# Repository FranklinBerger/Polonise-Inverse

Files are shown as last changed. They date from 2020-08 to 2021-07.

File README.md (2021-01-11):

# Calculatrice Polonaise Inversse

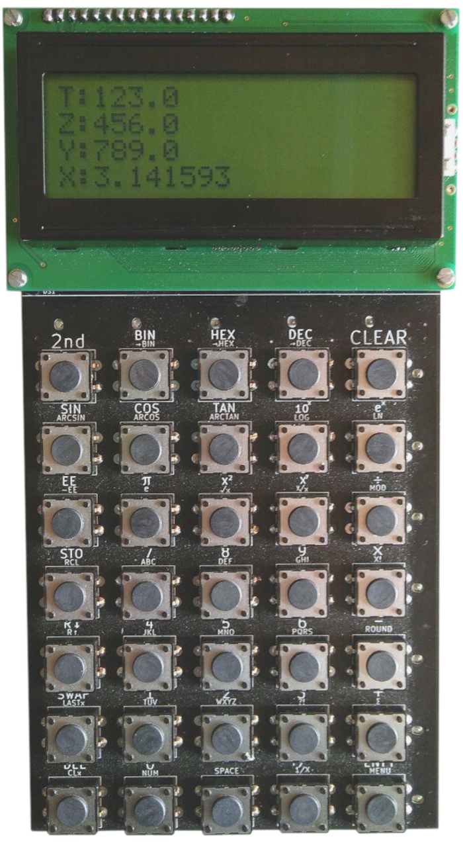
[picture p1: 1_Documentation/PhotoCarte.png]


<p><strong>/!\ Projet en cours de développement vers une verssion stable et correctement doccumentée /!\</strong></p>

Commencé dans le cadre d'un mois de découverte de l'électronique, ce projet consiste en une calculatrice avec [notation en polonaise inversse](https://fr.wikipedia.org/wiki/Notation_polonaise_inverse) dont le hardware est propice à la découverte et l'initiation à l'électronique, soit:
* Montage
* Développement
* Mesures & Dépannage
* Programation

Basée sur ESP32 et dévelopée sur un firware [Micropython](https://github.com/micropython), elle est propice à une compréhenssion de sa structure fondamentale et à des réalisations pratique très rapidement

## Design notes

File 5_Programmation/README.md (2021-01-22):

# Historique des versions
## V1: 22 Janvier 2021
Première version entière, comprenant
* Fonctionnement de base de la caulculatrice (gestion de l'écrant, du clavier, etc...)
* Fonctionnement de toutes les opérations mathématiques disponibles
* Fonctionnement de la gestion de la pile

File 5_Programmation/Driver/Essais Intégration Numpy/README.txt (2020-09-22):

Dans le but de rendre plus puissante et précise la calculatrice, une tentative d'intégrer la bibliothèque numpy a été réalisé. Celui-ci s'est avéré complexe car, hors problèmes de compatibilité dont quelques avancées ont déjà été réalisées (voir backend.py), la plus grande limite rencontrée a été la flash du uC que la bibliothèque surchargeait à l'initialisation (d'où la "compression" du code au travers de mpy-cross). Cette tentative a été abandonnée.

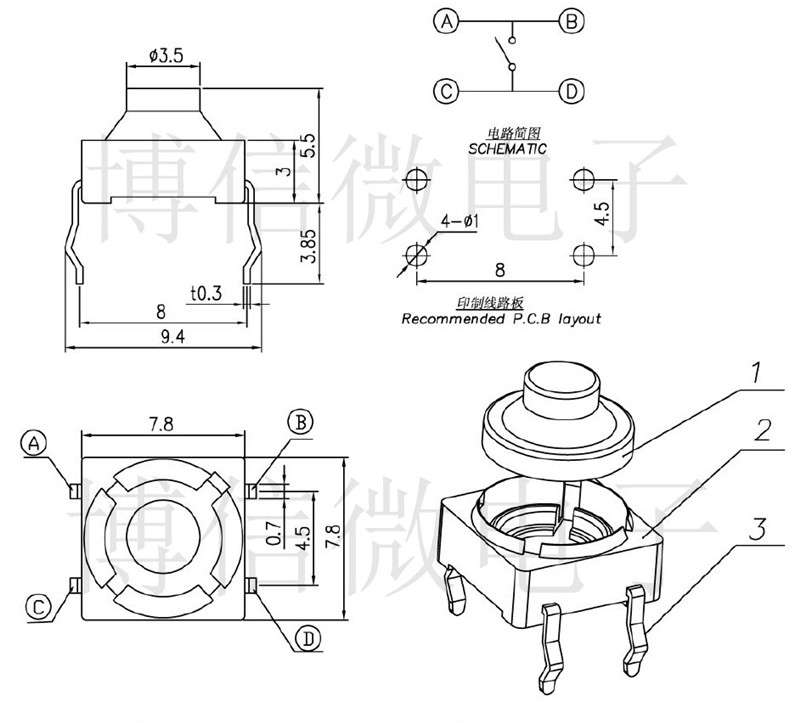
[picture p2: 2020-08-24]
3_Datasheets/BP.jpg

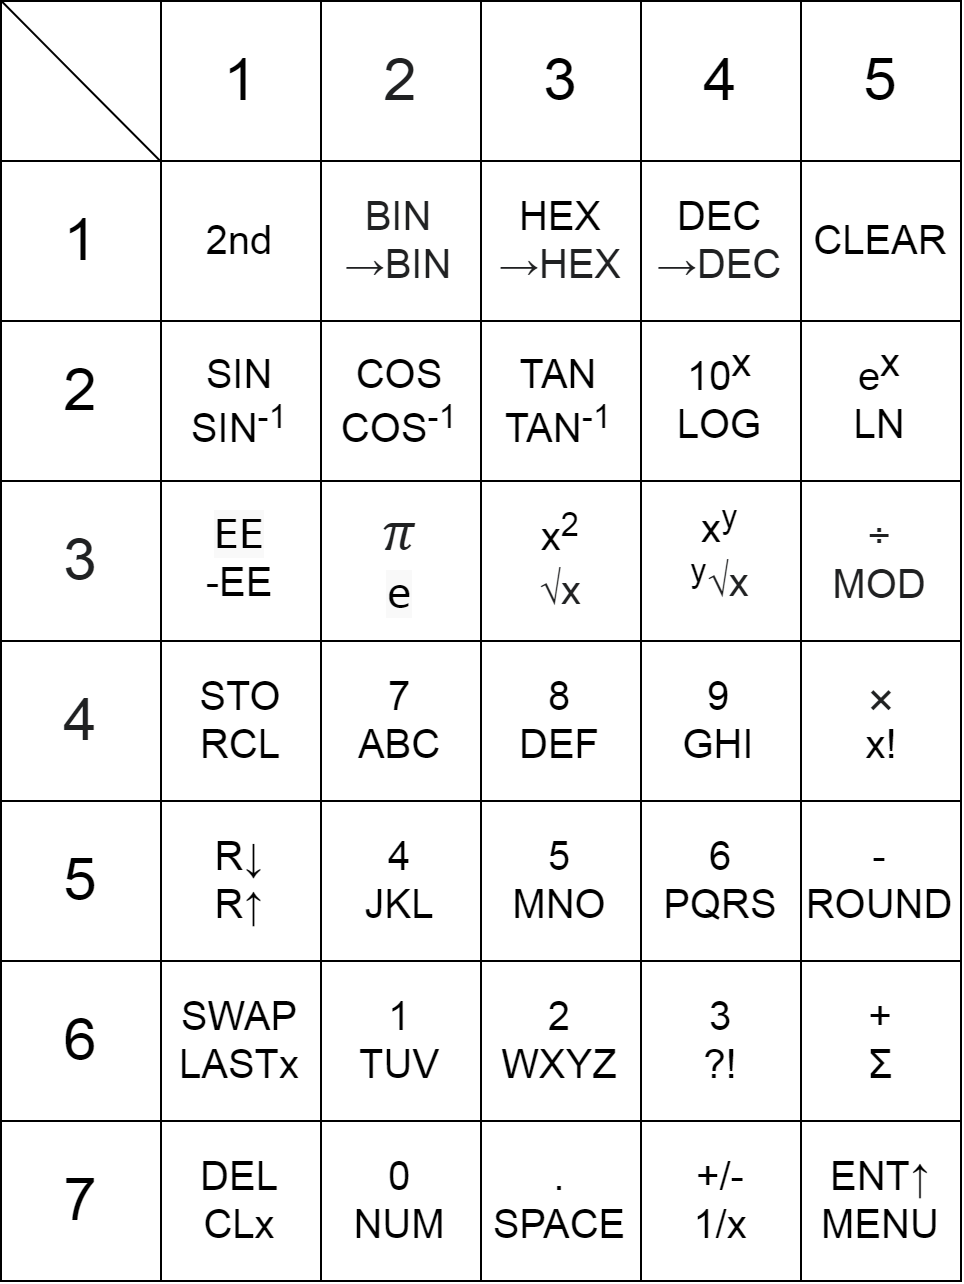
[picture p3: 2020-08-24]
1_Documentation/Clavier.png

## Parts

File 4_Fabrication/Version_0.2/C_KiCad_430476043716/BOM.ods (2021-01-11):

Référence | Valleur | N° Digikey | N° Divers | Qtt | Prix/Pce | Prix | Remarque
BT1 - 1 | Litium 18650 3.7[V] | 1832-1050-ND | Conrad 1558873 - 62 | 1 | 5,95 | 5,95
BT1 - 2 | Battery Holder | BK-18650-PC2-ND | Conrad 651027 - 62 | 1 | 3,45 | 3,45
> C1, C2, C6-C17 | 100[nF] | 399-C1206C104K5RAC7800CT-ND |  | 14 | 0,0413 | 0,5782
> C3, C4 | 33[μF] | 399-4788-1-ND |  | 2 | 0,97 | 1,94
> D1-D13 | 1206 Led rouge | 754-1158-1-ND |  | 13 | 0,27 | 3,51
DS1 - 1 | LCD2004A | NHD-0420DZ-FL-YBW-33V3-ND |  | 1 | 23,25 | 23,25
DS1 - 2 | Pin Header & receptacle 1x16 | 732-5327-ND & S7014-ND | Conrad 733779 - 62 | 1 | 1,15 | 1,15
DS1 - 3 | 4 x Vis + Ecrous + Rondelle + Collon. M2,5 |  |  | 4 | 0,34 | 1,36
J1 - 1 | FT232RL + Câble Mini-USB B | 768-1317-ND |  | 1 | 7,78 | 0, | Pour programation, non-consomable
J1 - 2 | Conn pour J1 | S5481-ND |  | 1 | 0,66 | 0,66
L1 | 2.2[μH] | 587-3544-1-ND |  | 1 | 0,1076 | 0,1076
> Q1-Q6 | BC856B | BC856BLT3GOSCT-ND |  | 6 | 0,0051 | 0,0306
> R1, R2, R25, R27, R29, R31, R33, R36 | 1[KΩ] | 311-1.0KERCT-ND |  | 8 | 0,0249 | 0,1992
> R3, R4, R17-R24, R26, R28, R30, R32, R34 | 10[KΩ] | 311-10KERCT-ND |  | 15 | 0,0249 | 0,3735
> R5-R16, R37 | 330[Ω] | 311-330FRCT-ND |  | 13 | 0,0291 | 0,3783
R35 | 5.6[Ω] | 311-5.60FRCT-ND |  | 1 | 0,14 | 0,14
RV1 | 10[KΩ] | 987-1008-1-ND |  | 1 | 1,27 | 1,27
> SW1, SW2 | BP Wuerth_4.5x6.5mm | 450-1647-ND |  | 2 | 0,1216 | 0,2432
> SW3-SW37 | BP 430476043716 12x12mm | 430476043716-ND |  | 35 | 0,54 | 18,9
SW38 | Switch SK-12F14 | Distrelek 135-11-185 |  | 1 | 0,63 | 0,63
U1 - 1 | Wavga_TP4056_Module |  |  | 1 | 1, | 1,
U1 - 2 | Pin Header 1x2 & 2x2 |  |  | 6 | 0,001 | 0,006
U2 | TPS63001 | 296-19643-1-ND |  | 1 | 2,21 | 2,21
U3 | ESP32-WROOM-32 | 1904-1010-1-ND | Conrad 1925467 - 62 | 1 | 3,8 | 3,8
U4 | PCF8574A | 568-1074-1-ND |  | 1 | 1,44 | 1,44
Print | Print |  |  | 1 | 16 | 16, | Via Eurocircuit, 20pcs Noir
 |  |  |  |  | Total: | 88,5766
 |  |  |  |  | 296-19643-1-ND
 |  |  |  |  | 1904-1010-1-ND
 |  |  |  |  | 568-1074-1-ND

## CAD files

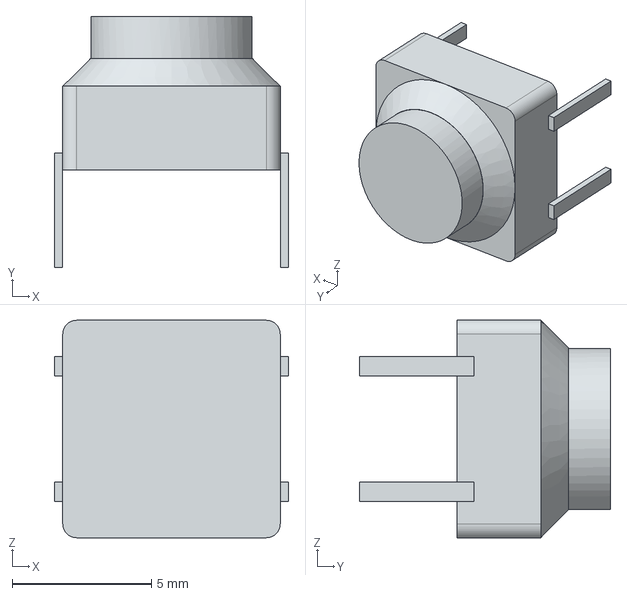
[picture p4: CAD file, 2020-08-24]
4_Fabrication/Version_0.2/C_KiCad_430476043716/G77.stp
8.40 x 9.00 x 7.80 mm

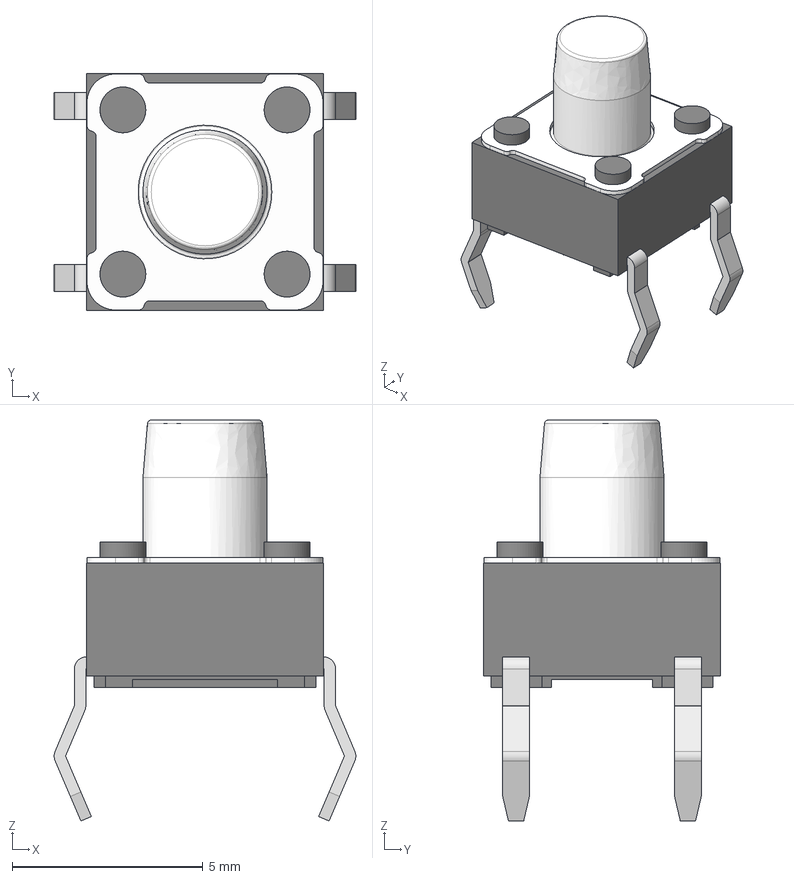
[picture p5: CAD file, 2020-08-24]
4_Fabrication/Version_0.2/C_KiCad_430476043716/shapes3D/SW_Wuert_6.5x4.5.stp
7.90 x 6.20 x 10.5 mm

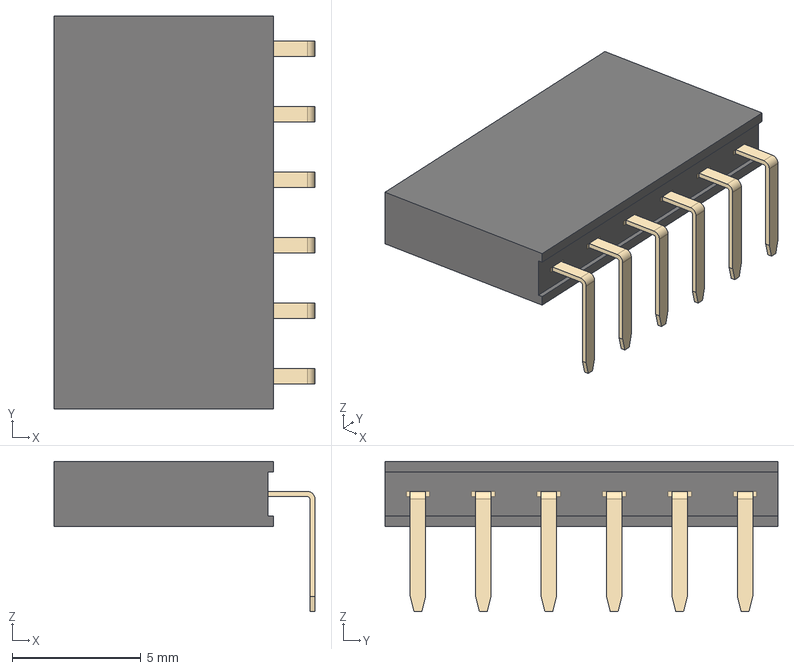
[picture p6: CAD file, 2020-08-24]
4_Fabrication/Version_0.2/C_KiCad_430476043716/shapes3D/PinSocket_1x06_P2.54mm_Horizontal.step
10.1 x 15.2 x 5.84 mm

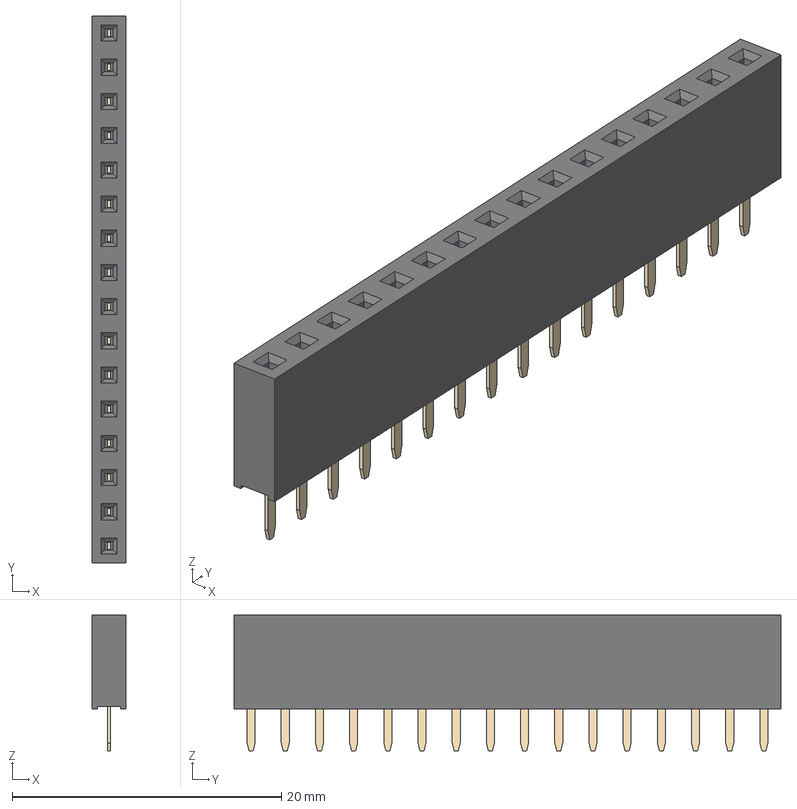
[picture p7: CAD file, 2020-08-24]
4_Fabrication/Version_0.2/C_KiCad_430476043716/shapes3D/PinSocket_1x16_P2.54mm_Vertical.step
2.54 x 40.6 x 10.1 mm

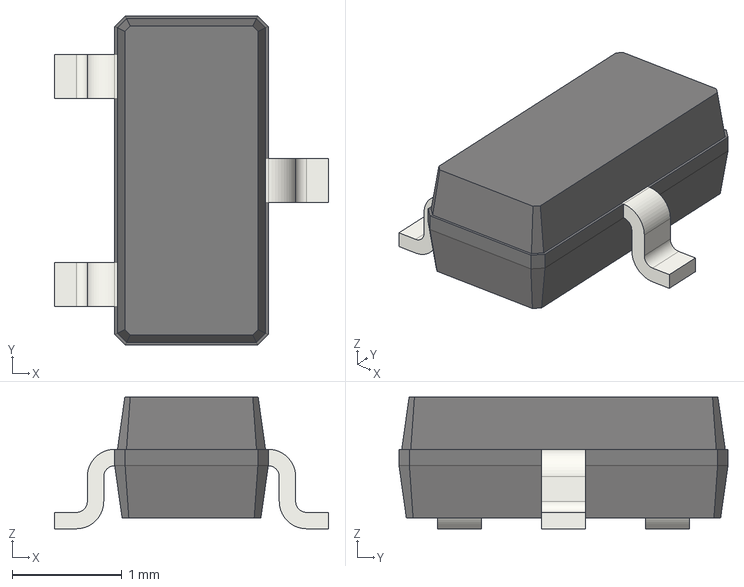
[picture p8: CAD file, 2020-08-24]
4_Fabrication/Version_0.2/C_KiCad_430476043716/shapes3D/SOT-23.step
2.50 x 3.00 x 1.20 mm

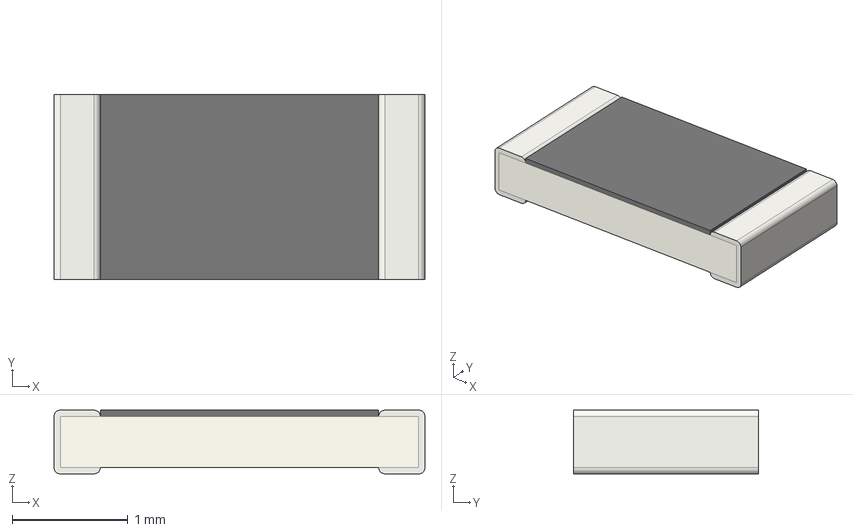
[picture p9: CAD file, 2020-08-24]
4_Fabrication/Version_0.2/C_KiCad_430476043716/shapes3D/R_1206_3216Metric.step
3.20 x 1.60 x 0.55 mm

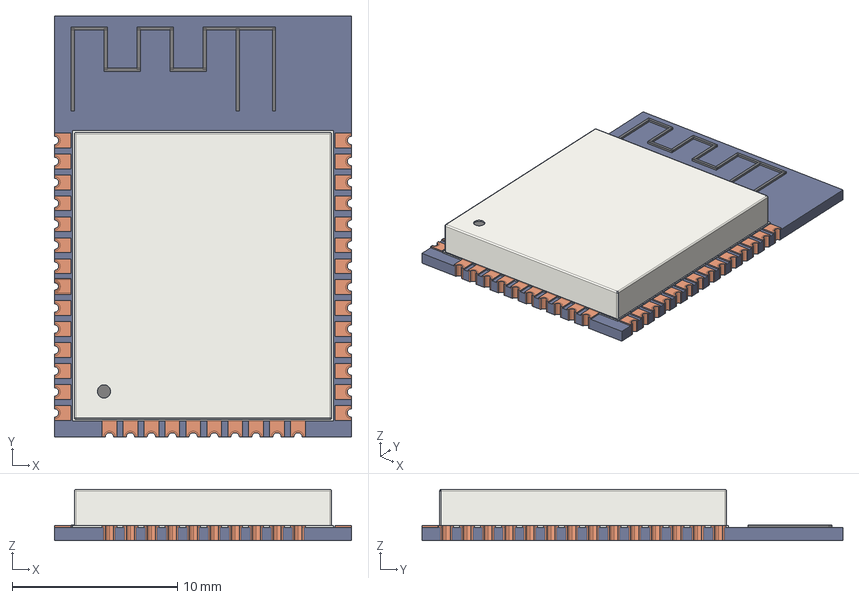
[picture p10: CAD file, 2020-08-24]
4_Fabrication/Version_0.2/C_KiCad_430476043716/shapes3D/ESP32-WROOM-32.step
18.0 x 25.5 x 3.10 mm

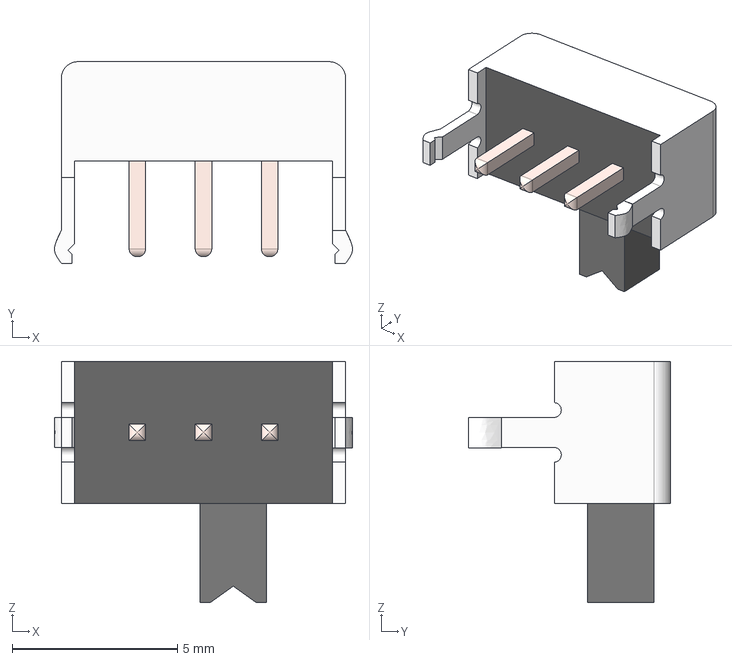
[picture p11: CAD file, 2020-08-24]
4_Fabrication/Version_0.2/C_KiCad_430476043716/shapes3D/Button_Switch_THTSW_CuK_OS102011MA1QN1_SPDT_Angled.step
9.01 x 6.10 x 7.30 mm

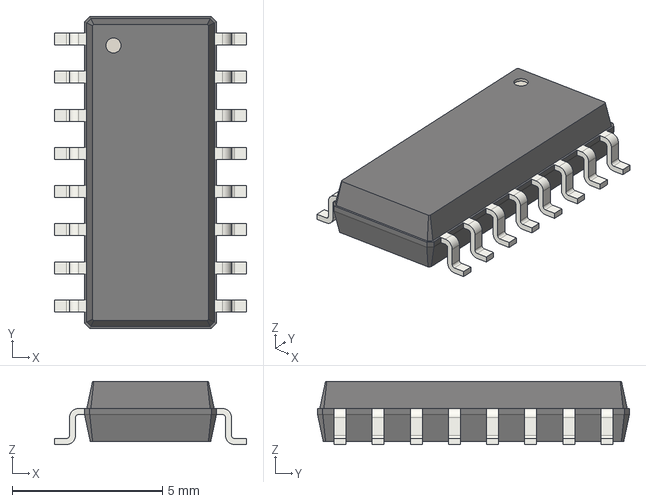
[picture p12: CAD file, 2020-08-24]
4_Fabrication/Version_0.2/C_KiCad_430476043716/shapes3D/SOP-16_4.4x10.4mm_P1.27mm.step
6.40 x 10.4 x 2.10 mm

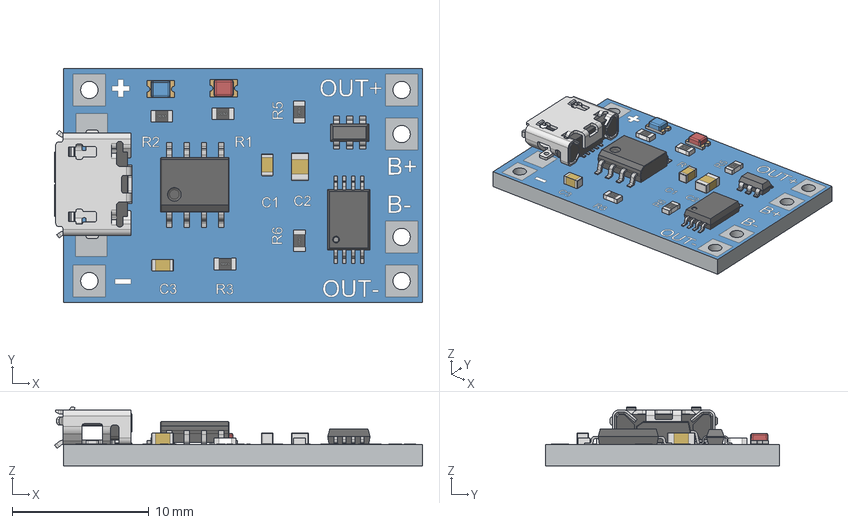
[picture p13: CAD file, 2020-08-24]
4_Fabrication/Version_0.2/C_KiCad_430476043716/shapes3D/LipoCharger-WithLoadProtection.stp
26.9 x 17.1 x 4.28 mm
bOARD
0603 Capacitor x 2
0603 Resistor x 5
0805 Capacitor
SOIC-8-150
LED - 0805 - Blue
LED - 0805 - Red
USB - Micro
tsop8
sot-23-6-2

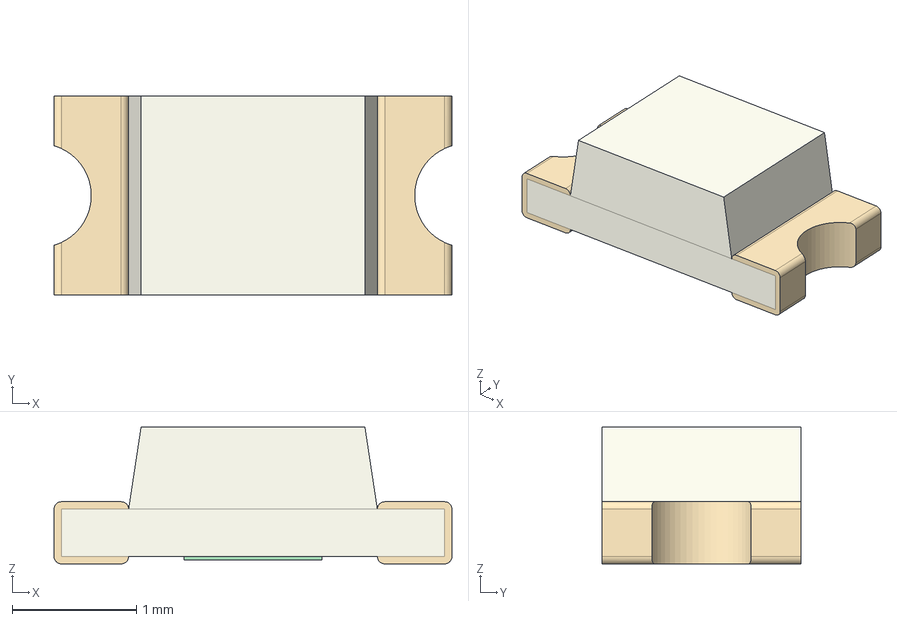
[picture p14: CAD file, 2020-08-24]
4_Fabrication/Version_0.2/C_KiCad_430476043716/shapes3D/LED_1206_3216Metric_Castellated.step
3.20 x 1.60 x 1.10 mm

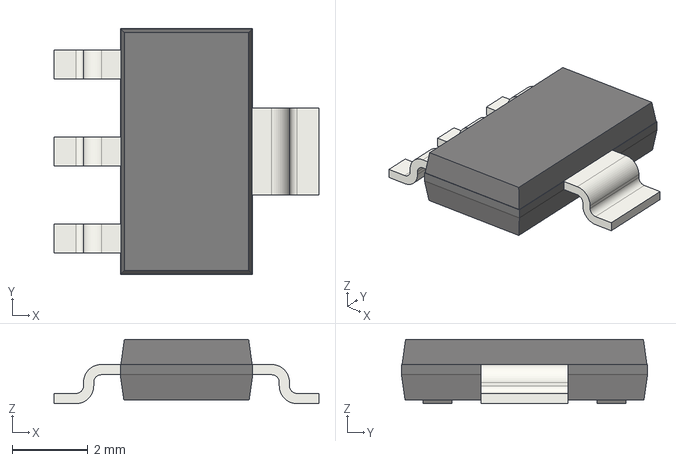
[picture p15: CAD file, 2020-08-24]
4_Fabrication/Version_0.2/C_KiCad_430476043716/shapes3D/SOT-223.step
7.00 x 6.50 x 1.70 mm

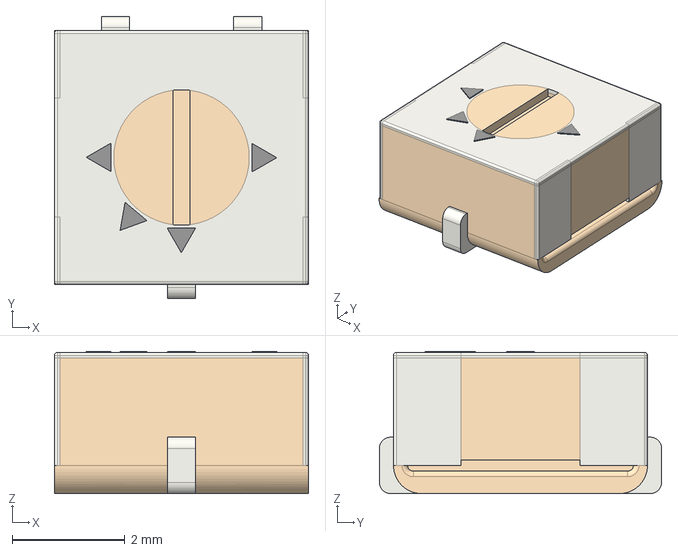
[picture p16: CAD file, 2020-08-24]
4_Fabrication/Version_0.2/C_KiCad_430476043716/shapes3D/Potentiometer_Bourns_3314J_Vertical.step
4.50 x 5.00 x 2.52 mm

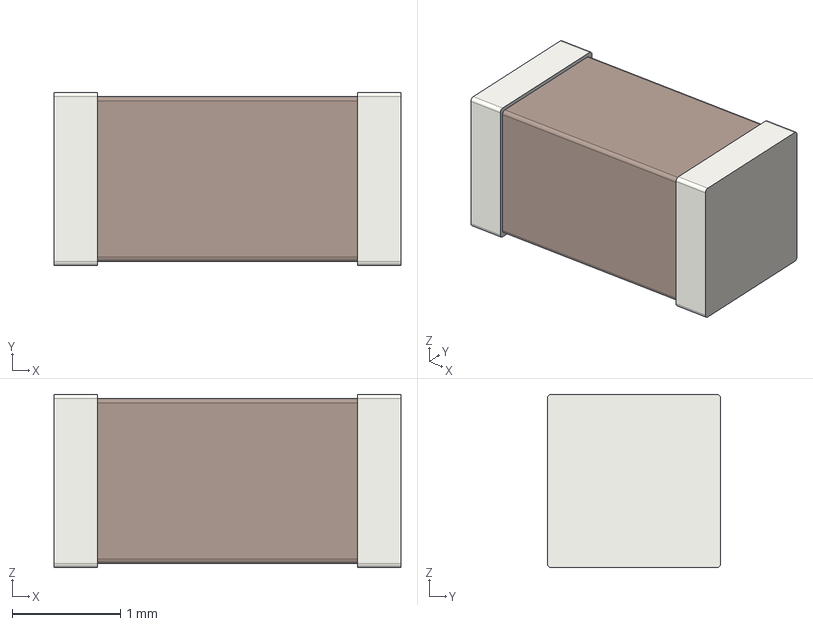
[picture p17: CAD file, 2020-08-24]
4_Fabrication/Version_0.2/C_KiCad_430476043716/shapes3D/C_1206_3216Metric.step
3.20 x 1.60 x 1.60 mm

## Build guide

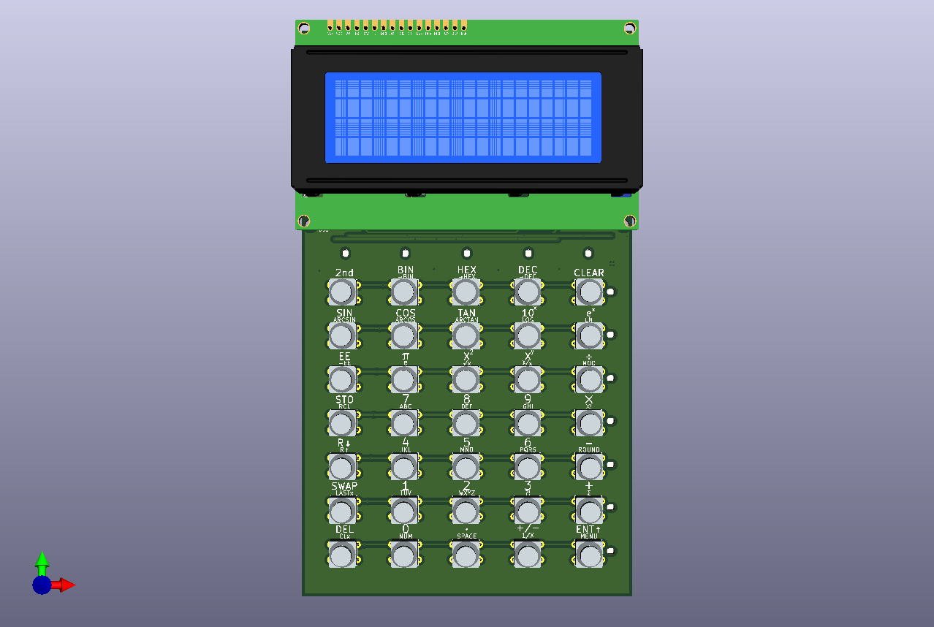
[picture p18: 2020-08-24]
4_Fabrication/Version_0.2/C_KiCad_430476043716/projet.png

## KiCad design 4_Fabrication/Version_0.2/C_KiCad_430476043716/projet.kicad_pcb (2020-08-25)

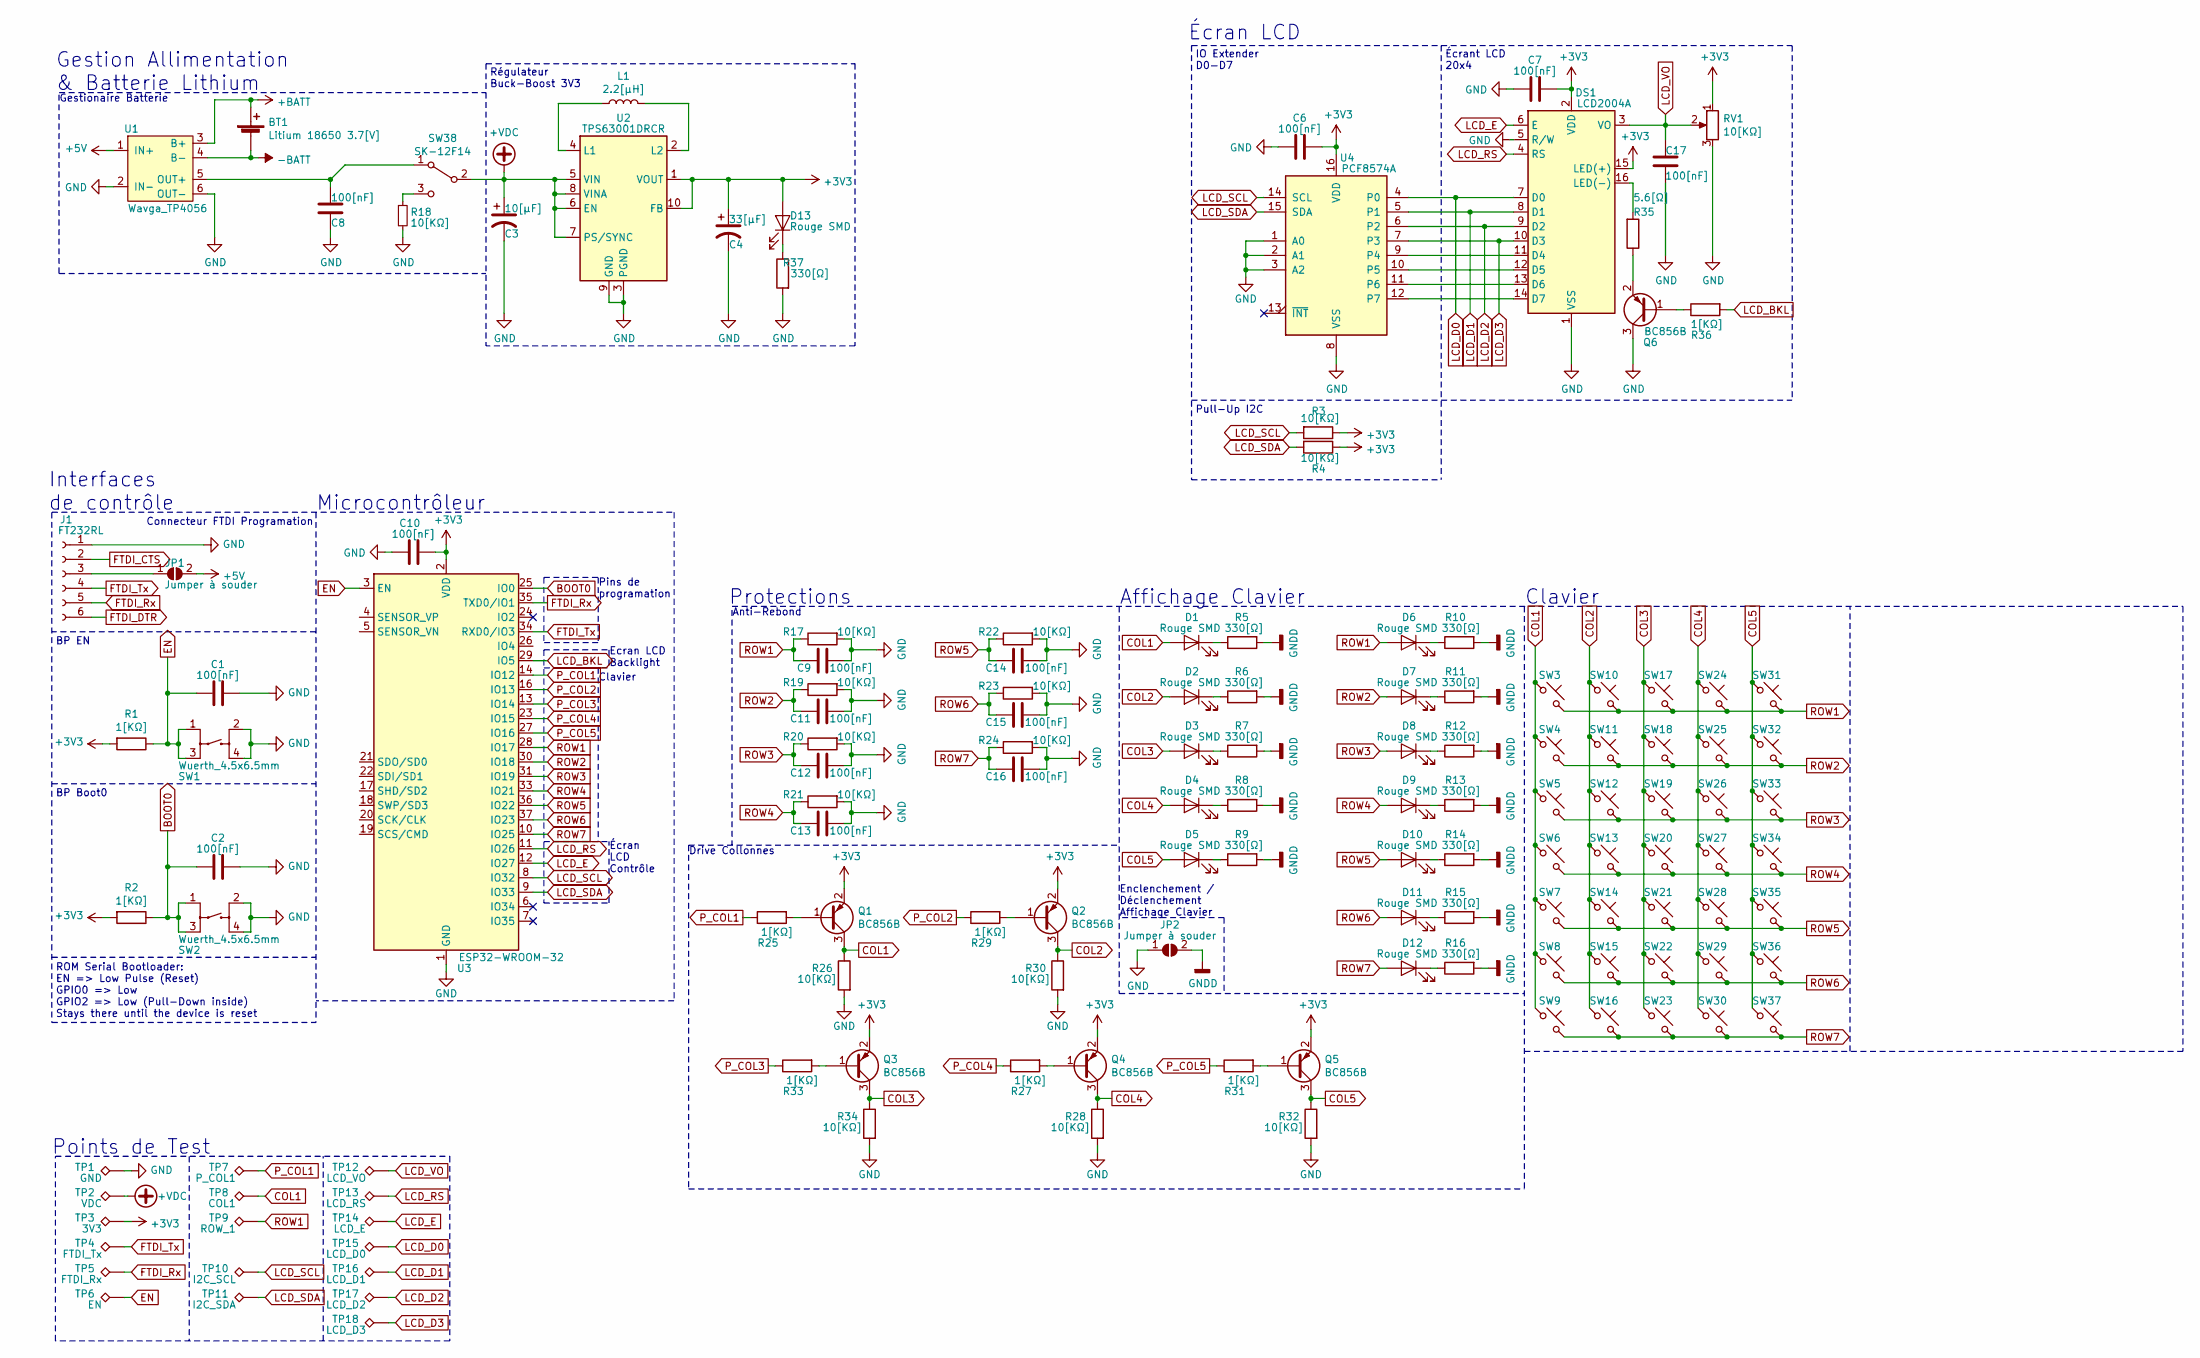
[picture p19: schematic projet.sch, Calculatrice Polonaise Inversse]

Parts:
BT1: Litium 18650 3.7[V]; BatteryHolder_Aliexpress_XZT_18650
C1, C2, C6, C7, C8, C9, C10, C11, C12, C13, C14, C15, C16, C17: 100[nF]; C_1206_3216Metric_Pad1.42x1.75mm_HandSolder
C3: 10[μF]; C_1206_3216Metric_Pad1.42x1.75mm_HandSolder
C4: 33[μF]; C_1206_3216Metric_Pad1.42x1.75mm_HandSolder
D1, D2, D3, D4, D5, D6, D7, D8, D9, D10, D11, D12, D13: Rouge SMD; LED_1206_3216Metric_ReverseMount_Hole1.8x2.4mm
DS1: LCD2004A; LCD2004A_TOP
J1: FT232RL; PinSocket_1x06_P2.54mm_Horizontal
JP1, JP2: Jumper à souder; SolderJumper-2_P1.3mm_Open_TrianglePad1.0x1.5mm
L1: 2.2[μH]; L_Taiyo-Yuden_NR-24xx_HandSoldering
Q1, Q2, Q3, Q4, Q5, Q6: BC856B; SOT-23_Handsoldering
R1, R2, R25, R27, R29, R31, R33, R36: 1[KΩ]; R_1206_3216Metric_Pad1.42x1.75mm_HandSolder
R3, R4, R17, R18, R19, R20, R21, R22, R23, R24, R26, R28, R30, R32, R34: 10[KΩ]; R_1206_3216Metric_Pad1.42x1.75mm_HandSolder
R5, R6, R7, R8, R9, R10, R11, R12, R13, R14, R15, R16, R37: 330[Ω]; R_1206_3216Metric_Pad1.42x1.75mm_HandSolder
R35: 5.6[Ω]; R_1206_3216Metric_Pad1.42x1.75mm_HandSolder
RV1: 10[KΩ]; Potentiometer_Bourns_3224J_Horizontal
SW1, SW2: Wuerth_4.5x6.5mm; SW_Wuerth_6.5x4.5mm
SW3, SW4, SW5, SW6, SW7, SW8, SW9, SW10, SW11, SW12, SW13, SW14, SW15, SW16, SW17, SW18, SW19, SW20, SW21, SW22, SW23, SW24, SW25, SW26, SW27, SW28, SW29, SW30, SW31, SW32, SW33, SW34, SW35, SW36, SW37: G77; SW_PUSH-12mm_Wuerth-430476085716
SW38: SK-12F14; SW_CuK_OS102011MA1QN1_SPDT_Angled
TP1: GND; TestPoint_Pad_1.5x1.5mm
TP2: VDC; TestPoint_Pad_1.5x1.5mm
TP3: 3V3; TestPoint_Pad_1.5x1.5mm
TP4: FTDI_Tx; TestPoint_Pad_1.5x1.5mm
TP5: FTDI_Rx; TestPoint_Pad_1.5x1.5mm
TP6: EN; TestPoint_Pad_1.5x1.5mm
TP7: P_COL1; TestPoint_Pad_1.5x1.5mm
TP8: COL1; TestPoint_Pad_1.5x1.5mm
TP9: ROW_1; TestPoint_Pad_1.5x1.5mm
TP10: I2C_SCL; TestPoint_Pad_1.5x1.5mm
TP11: I2C_SDA; TestPoint_Pad_1.5x1.5mm
TP12: LCD_VO; TestPoint_Pad_1.5x1.5mm
TP13: LCD_RS; TestPoint_Pad_1.5x1.5mm
TP14: LCD_E; TestPoint_Pad_1.5x1.5mm
TP15: LCD_D0; TestPoint_Pad_1.5x1.5mm
TP16: LCD_D1; TestPoint_Pad_1.5x1.5mm
TP17: LCD_D2; TestPoint_Pad_1.5x1.5mm
TP18: LCD_D3; TestPoint_Pad_1.5x1.5mm
U1: Wavga_TP4056; Wavgat_TP4056
U2: TPS63001DRCR; Texas_DRC0010J_ThermalVias
U3: ESP32-WROOM-32
U4: PCF8574A; SOIC-16W_7.5x10.3mm_P1.27mm

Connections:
+3V3: C4.1, C6.2, C7.2, C10.2, D13.2 (A), DS1.2 (VDD), DS1.15 (LED(+)), Q1.2 (E), Q2.2 (E), Q3.2 (E), Q4.2 (E), Q5.2 (E), R1.2, R2.2, R3.1, R4.1, RV1.1, TP3.1, U2.1 (VOUT), U2.10 (FB), U3.2 (VDD), U4.16 (VDD)
+5V: JP1.2 (B), U1.1 (IN+)
+BATT: BT1.1 (+), U1.3 (B+)
+VDC: C3.1, SW38.2 (B), TP2.1, U2.5 (VIN), U2.6 (EN), U2.7 (PS/SYNC), U2.8 (VINA)
-BATT: BT1.2 (-), U1.4 (B-)
BOOT0: C2.1, R2.1, SW2.1, SW2.3, U3.25 (IO0)
COL1: D1.2 (A), Q1.3 (C), R26.1, SW3.1, SW4.1, SW5.1, SW6.1, SW7.1, SW8.1, SW9.1, TP8.1
COL2: D2.2 (A), Q2.3 (C), R30.1, SW10.1, SW11.1, SW12.1, SW13.1, SW14.1, SW15.1, SW16.1
COL3: D3.2 (A), Q3.3 (C), R34.1, SW17.1, SW18.1, SW19.1, SW20.1, SW21.1, SW22.1, SW23.1
COL4: D4.2 (A), Q4.3 (C), R28.1, SW24.1, SW25.1, SW26.1, SW27.1, SW28.1, SW29.1, SW30.1
COL5: D5.2 (A), Q5.3 (C), R32.1, SW31.1, SW32.1, SW33.1, SW34.1, SW35.1, SW36.1, SW37.1
EN: C1.1, R1.1, SW1.1, SW1.3, TP6.1, U3.3 (EN)
FTDI_CTS: J1.2
FTDI_DTR: J1.6
FTDI_Rx: J1.5, TP5.1, U3.35 (TXD0/IO1)
FTDI_Tx: J1.4, TP4.1, U3.34 (RXD0/IO3)
GND: C1.2, C2.2, C3.2, C4.2, C6.1, C7.1, C8.2, C9.2, C10.1, C11.2, C12.2, C13.2, C14.2, C15.2, C16.2, C17.1, DS1.1 (VSS), DS1.5 (R/W), J1.1, JP2.1 (A), Q6.3 (C), R17.2, R18.2, R19.2, R20.2, R21.2, R22.2, R23.2, R24.2, R26.2, R28.2, R30.2, R32.2, R34.2, R37.2, RV1.3, SW1.2, SW1.4, SW2.2, SW2.4, TP1.1, U1.2 (IN-), U1.6 (OUT-), U2.3 (PGND), U2.9 (GND), U2.11 (PGND), U3.1 (GND), U3.15 (GND), U3.38 (GND), U3.39 (GND), U4.1 (A0), U4.2 (A1), U4.3 (A2), U4.8 (VSS)
GNDD: JP2.2 (B), R5.2, R6.2, R7.2, R8.2, R9.2, R10.2, R11.2, R12.2, R13.2, R14.2, R15.2, R16.2
LCD_BKL: R36.2, U3.29 (IO5)
LCD_D0: DS1.7 (D0), TP15.1, U4.4 (P0)
LCD_D1: DS1.8 (D1), TP16.1, U4.5 (P1)
LCD_D2: DS1.9 (D2), TP17.1, U4.6 (P2)
LCD_D3: DS1.10 (D3), TP18.1, U4.7 (P3)
LCD_E: DS1.6 (E), TP14.1, U3.12 (IO27)
LCD_RS: DS1.4 (RS), TP13.1, U3.11 (IO26)
LCD_SCL: R3.2, TP10.1, U3.8 (IO32), U4.14 (SCL)
LCD_SDA: R4.2, TP11.1, U3.9 (IO33), U4.15 (SDA)
LCD_VO: C17.2, DS1.3 (VO), RV1.2, TP12.1
unnamed: C8.1, SW38.1 (A), U1.5 (OUT+)
unnamed: D1.1 (K), R5.1
unnamed: D2.1 (K), R6.1
unnamed: D3.1 (K), R7.1
unnamed: D4.1 (K), R8.1
unnamed: D5.1 (K), R9.1
unnamed: D6.1 (K), R10.1
unnamed: D7.1 (K), R11.1
unnamed: D8.1 (K), R12.1
unnamed: D9.1 (K), R13.1
unnamed: D10.1 (K), R14.1
unnamed: D11.1 (K), R15.1
unnamed: D12.1 (K), R16.1
unnamed: D13.1 (K), R37.1
unnamed: DS1.11 (D4), U4.9 (P4)
unnamed: DS1.12 (D5), U4.10 (P5)
unnamed: DS1.13 (D6), U4.11 (P6)
unnamed: DS1.14 (D7), U4.12 (P7)
unnamed: DS1.16 (LED(-)), R35.2
unnamed: J1.3, JP1.1 (A)
unnamed: L1.1, U2.4 (L1)
unnamed: L1.2, U2.2 (L2)
unnamed: Q1.1 (B), R25.2
unnamed: Q2.1 (B), R29.2
unnamed: Q3.1 (B), R33.2
unnamed: Q4.1 (B), R27.2
unnamed: Q5.1 (B), R31.2
unnamed: Q6.1 (B), R36.1
unnamed: Q6.2 (E), R35.1
unnamed: R18.1, SW38.3 (C)
P_COL1: R25.1, TP7.1, U3.14 (IO12)
P_COL2: R29.1, U3.16 (IO13)
P_COL3: R33.1, U3.13 (IO14)
P_COL4: R27.1, U3.23 (IO15)
P_COL5: R31.1, U3.27 (IO16)
ROW1: C9.1, D6.2 (A), R17.1, SW3.2, SW10.2, SW17.2, SW24.2, SW31.2, TP9.1, U3.28 (IO17)
ROW2: C11.1, D7.2 (A), R19.1, SW4.2, SW11.2, SW18.2, SW25.2, SW32.2, U3.30 (IO18)
ROW3: C12.1, D8.2 (A), R20.1, SW5.2, SW12.2, SW19.2, SW26.2, SW33.2, U3.31 (IO19)
ROW4: C13.1, D9.2 (A), R21.1, SW6.2, SW13.2, SW20.2, SW27.2, SW34.2, U3.33 (IO21)
ROW5: C14.1, D10.2 (A), R22.1, SW7.2, SW14.2, SW21.2, SW28.2, SW35.2, U3.36 (IO22)
ROW6: C15.1, D11.2 (A), R23.1, SW8.2, SW15.2, SW22.2, SW29.2, SW36.2, U3.37 (IO23)
ROW7: C16.1, D12.2 (A), R24.1, SW9.2, SW16.2, SW23.2, SW30.2, SW37.2, U3.10 (IO25)

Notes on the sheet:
Gestion Allimentation & Batterie Lithium
Gestionaire Batterie
Régulateur Buck-Boost 3V3
BP EN
BP Boot0
Connecteur FTDI Programation
Interfaces de contrôle
Pins de programation
ROM Serial Bootloader: EN => Low Pulse (Reset) GPIO0 => Low GPIO2 => Low (Pull-Down inside) Stays there until the device is reset
Clavier
Écran LCD Contrôle
Microcontrôleur
Affichage Clavier
Enclenchement / Déclenchement Affichage Clavier
IO Extender D0-D7
Écrant LCD 20x4
Pull-Up I2C
Écran LCD
Protections
Anti-Rebond
Drive Collonnes
Points de Test
Ecran LCD Backlight

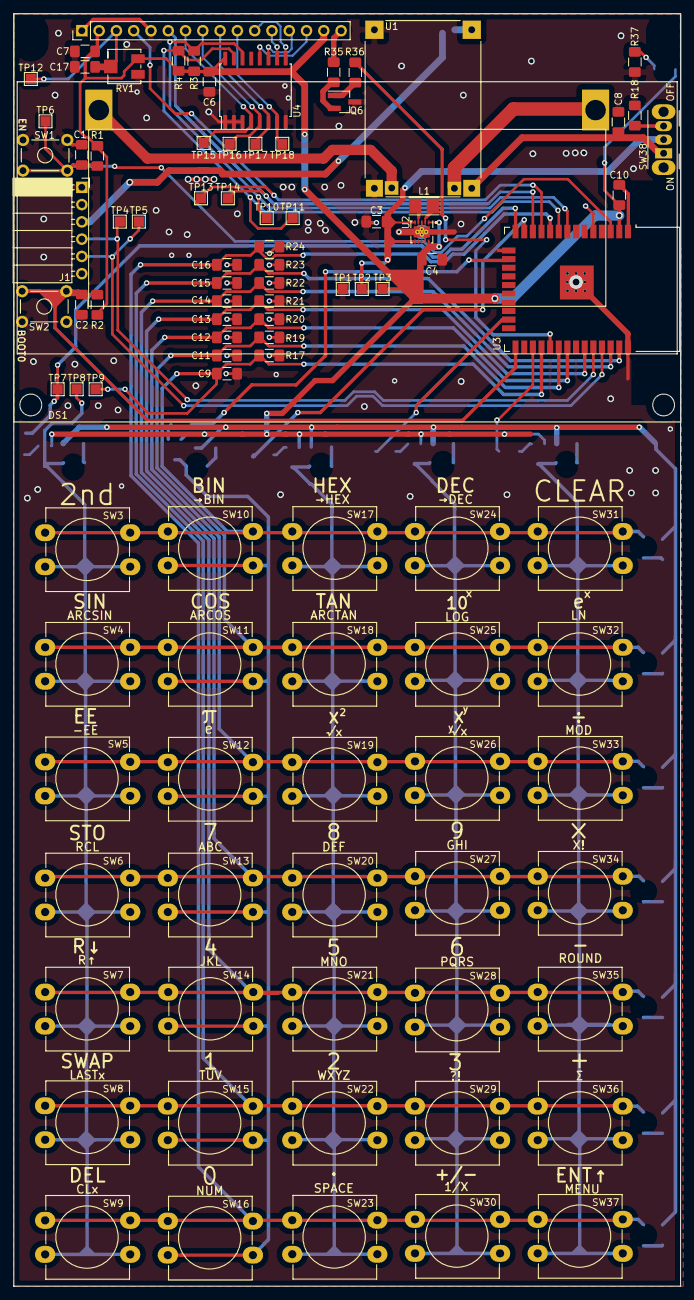
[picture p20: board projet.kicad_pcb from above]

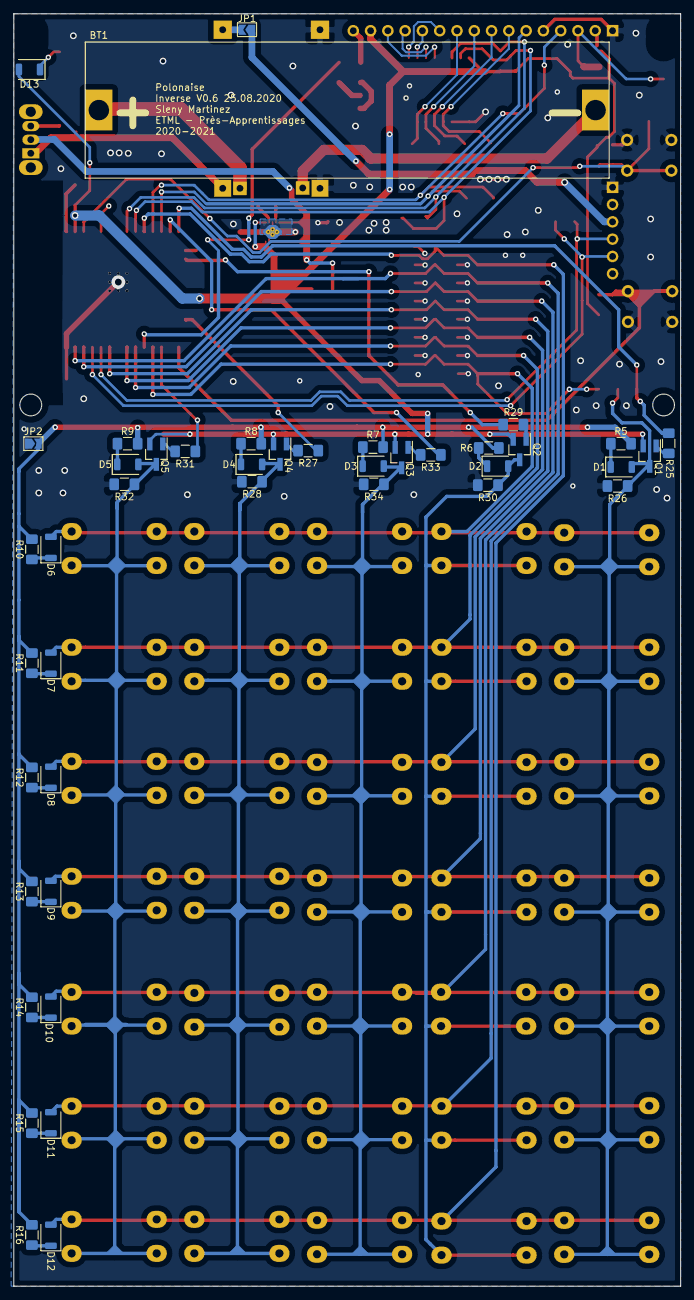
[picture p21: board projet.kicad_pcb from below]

Board: 2 copper layers, 98.0 x 187.0 mm, 139 parts (43 on the bottom side), 68 nets.

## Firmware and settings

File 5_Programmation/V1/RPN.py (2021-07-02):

# CONSTANTES & PARAMETRES
import micropython
DEBUG_MODE = micropython.const(False)

doc="""
Fichier: RPN.py
Projet: Calculatrice Polonaise Inversse V0.5
Verssion & Date: V1 05.08.2020

Description:
Systeme de calcul sous format RPN (Polonaise inversse)
La pile est de 4 niveaux (X, Y, Z, T) avec duplication sur le niveau T
Des systemes de gestion de la pile (rotation, ecriture des niveaux, etc...)
sont contenu ainsi que de nombreuses fonctions mathematiques communes
Tous les nombres sont contenu au format flotant decimal. On pourra les
recuperer sous ce format via get ( layer ) ou arrondi sans perte via getInt( layer )
Gestion aussi de l'ecriture d'une valleur X via

Contenu:


Auteur·e:
- Sleny Martinez (MAS)
- XXX XXX
"""


""" ------ Imports ------ """
# Gestion des exceptions etendue en cas de debug
if DEBUG_MODE: micropython.alloc_emergency_exception_buf(128)

# Imports bibliotheques interne
import machine
import math

# Imports bibliotheques externe officielle (lib)
#import mpmath

# Imports bibliotheques externe maisons




""" ------ Code Utile ------ """
" --- Initialisation --- "
# Initialisation des niveaux de la pile
# TrueX definit si le X actuel est vrais ou seulement
# la persistence d'afichage apres un ENT
# Ceci permet de dupliquer X si plusieurs ENT a la suite
_pile = {
    "X" : "0" ,
    "Y" : 0.0 ,
    "Z" : 0.0 ,
    "T" : 0.0 ,
    "TrueX" : False ,
    "AfterEnt" : False ,
    "LastX" : 0
}

" --- Systeme --- "
# --- Controle des niveaux de la pile
# Definit pour N = X, Y, Z et T:
# - set ( layer , val )
# - get ( layer )
# - getInt ( layer )

def getPile ():
    """
    Fonction: getPile ()
    Return la valleur la pile tel qu'elle est
    """
    global _pile
    return _pile

def set ( layer , val ):
    """
    Fonction: set ( layer , val )
    Modifie la valleur de l'etage layer de la pile
    """
    global _pile
    _pile[layer] = float( val ) if layer in "XYZT" else val

def get ( layer ):
    """
    Fonction: get ()
    Return la valleur la pile au niveau layer en float
    """
    try:
        return float( getPile()[layer] )
    except Exception:
        return int( getPile()[layer] )

def getInt ( layer ):
    """
    Fonction: getInt ()
    Return la valleur layer de la pile
    Si valleur ronde, la rend int, sinon la rend float
    """
    _pileL = get(layer)
    return int(_pileL) if int(_pileL) == _pileL else _pileL


# --- Ecriture de X
def _setX ( val ):
    """
    Fonction: setX ( val )
    Modifie la valleur de X en brut
    """
    global _pile
    _pile["X"] = val

def _getX ():
    """
    Fonction: getX ()
    Obtient la valeur de X en brut
    """
    global _pile
    return _pile["X"]

def writeX ( char ):
    """
    Fonction: writeX ( char )
    Ecriture de X
    Le caractere doit etre 0-9 ou .
    """
    # Si apres "Ent", on doit aire un shift up avant ecriture pour ne pas
    # supprimer notre resultat
    if get("AfterEnt"):
        shiftUp()
        set("AfterEnt", False)
    # Si TrueX a False (X = affichage), reecrit sur une base brut
    _setX( _getX() + char if get("TrueX") else char )
    set("TrueX", True)

def _actOnXY (newX):
    """
    Fonction: _actOnXY (newX)
    "Ecrase" Y dans X, X = newX
    """
    set("Y", newX)
    shiftDown()
    set("AfterEnt", True)

# --- Actions sur la pile ---
def swapXY ():
    """
    Fonction: swapXY ()
    Echange les valeurs de X et Y
    """
    oldX = get("X")
    set("X", get("Y"))
    set("Y", oldX)

def shiftUp ():
    """
    Fonction: shiftUp ()
    Equivalent de la fonction ENT
    Fait monter la pile d'un etage => libere la couche X
    A ne pas confondre avec rotateUp
    La valleur T sera perdue
    Enreistre la veleur dans LastX
    """
    set("T" , get("Z") )
    set("Z" , get("Y") )
    set("Y" , get("X") )
    set("LastX", get("X"))
    set("TrueX" , False )

def shiftDown ():
    """
    Fonction: shiftDown ()
    Fait descendre la pile d'un etage
    A ne pas confondre avec rotateDown
    La valleur X sera perdue
    La valleur T sera doublee dans Z
    """
    set("X" , get("Y") )
    set("Y" , get("Z") )
    set("Z" , get("T") )
    set("TrueX" , True )

def rotateUp ():
    """
    Fonction: rotateUp ()
    Fait tourner la le vers le haut
    A ne pas confondre avec shiftUp()
    """
    oldT = get("T")
    shiftUp()
    set("X", oldT)

def rotateDown ():
    """
    Fonction: rotateDown ()
    Fait tourner la le vers le bas
    A ne pas confondre avec shiftDown()
    """
    oldX = get("X")
    shiftDown()
    set("T", oldX)

def clear ():
    """
    Fonction: clear ()
    Remet toutes les valeurs de la pile a 0
    """
    global _pile
    _pile = {
        "X" : "0" ,
        "Y" : 0.0 ,
        "Z" : 0.0 ,
        "T" : 0.0 ,
        "TrueX" : False ,
        "AfterEnt" : False
    }

def lastX ():
    """
    Fonction: lastX ()
    Remet la derniere valeur de X entree (par shiftUp) dans X
    """
    set("X", get("LastX"))

def delX ():
    """
    Fonction: delX ()
    Supprime un caractere de X
    Si plus rien, met a 0
    Si X est un chiffre valide (p.ex apres addition), remet a 0
    """
    _setX( _getX()[:-1] if type(_getX()) == str and len(_getX()) > 1 else "0" )
    set("TrueX", False if _getX() == "0" else True)

def clearX ():
    """
    Fonction: clearX ()
    Met X a 0
    """
    _setX("0")
    set("TrueX", False)

# --- Actions mathematique ---
def opposite ():
    """
    Fonction: opposite ()
    Y + X
    """
    _setX(-get("X"))

def invert ():
    """
    1 / X
    """
    _setX( 1 / get("X"))

def add ():
    """
    Fonction: add ()
    Y + X
    """
    _actOnXY(get("Y") + get("X"))

def sigma ():
    """
    Fonction: sigma ()
    X = somme de tous les x de x a 1
    P.ex: sigma de 5 = 5+4+3+2+1 = 15
    On la calcul par f(x) = (x * (x+1)) / 2
    """
    x = get("X")
    _setX( ((x+1) * x) / 2 )

def subtract ():
    """
    Fonction: sub ()
    Y - X
    """
    _actOnXY(get("Y") - get("X"))

def round ():
    """
    Fonction: round ()
    X = round(X)
    """
    _setX( float( int( get("X") ) ) )

def multiply ():
    """
    Fonction: multiply ()
    Y * X
    """
    _actOnXY(get("Y") * get("X"))

def factorial ():
    """
    Fonction: factorial ()
    X = X!
    """
    x = 1
    for i in range(get("X"), 1, -1): x *= i
    _setX( x )

def divide ():
    """
    Fonction: add ()
    Y / X
    """
    _actOnXY(get("Y") / get("X"))

def modulo ():
    """
    Fonction: add ()
    Y % X
    """
    _actOnXY(get("Y") % get("X"))

def pi ():
    """
    Fonction: pi ()
    X = pi (3.141593)
    """
    _setX(math.pi)

def e ():
    """
    Fonction: e ()
    X = e (2.718282)
    """
    _setX(math.e)

def square ():
    """
    Fonction: square ()
    X = X^2
    """
    _setX( math.pow( get("X") , 2 ) )

def square_root ():
    """
    Fonction: square_root ()
    X = racine carree de X
    """
    _setX( math.pow( get("X") , (1/2) ) )

def power_to ():
    """
    Fonction: power_to ()
    X = Y^X
    """
    _actOnXY( math.pow( get("Y") , get("X") ) )

def root ():
    """
    Fonction: square_root ()
    X = racine Xeme de Y
    """
    _actOnXY( math.pow( get("Y") , (1/get("X")) ) )

def e_pow_x ():
    """
    Fonction: e_pow_x ()
    X = e ^ X
    """
    set("X" , math.pow( math.e , get("X") ) )

def ten_pow_x ():
    """
    Fonction: ten_pow_x ()
    X = 10 ^ X
    """
    set("X" , math.pow( 10 , get("X") ) )

def log ():
    """
    Fonction: log ()
    X = log10(X)
    """
    _setX( math.log10( get("X") ) )

def ln ():
    """
    Fonction: log ()
    X = ln(X)
    """
    _setX( math.log( get("X") ) )

def sin ():
    """
    Fonction: sin ()
    X = sin(X)
    """
    _setX( math.sin( get("X") ) )

def cos ():
    """
    Fonction: cos ()
    X = cos(X)
    """
    _setX( math.cos( get("X") ) )

def tan ():
    """
    Fonction: sin ()
    X = sin(X)
    """
    _setX( math.tan( get("X") )  )

def arcsin ():
    """
    Fonction: arcsin ()
    X = arcsin(X)
    """
    _setX( math.sinh( get("X") ) )

def arccos ():
    """
    Fonction: arccos ()
    X = arccos(X)
    """
    _setX( math.cosh( get("X") ) )

def arctan ():
    """
    Fonction: arcsin ()
    X = arcsin(X)
    """
    _setX( math.tanh( get("X") )  )

def toHex ():
    """
    Fonction: toHex ()
    X = sin(X)
    """
    _setX( hex( int( get("X") ) )  )

def toBin ():
    """
    Fonction: toHex ()
    X = sin(X)
    """
    _setX( bin( int( get("X") ) ) )

def toDec ():
    """
    Fonction: toHex ()
    X = sin(X)
    """
    _setX( get("X")  )


""" ------ Algoritme de presentation ------ """
if __name__ == "__main__":
    # Affichage doc du fichier
    print(doc)

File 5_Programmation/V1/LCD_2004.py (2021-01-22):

# CONSTANTES & PARAMETRES
import micropython
DEBUG_MODE = micropython.const(False)

doc="""
Fichier: LCD_2004.py
Projet: Calculatrice Polonaise Inversse V0.5
Verssion & Date: V1 15.08.2020

Dependances:
- PCF8574.py

Description:
Gestion d'affichage sur ecrant LCD 20x4 au travers d'un IO Extender PCF8574 et
avec gestion de la luminosite de la backlight de l'ecrant (via PWM @ 1[KHz])
Les pins E (Enable) et RS (Commande Data / Instruction) sont controlees en directe,
la pin R/W (Ecriture / Lecture) est maintenue en lecture (GND)
Le systeme fonctionne sous la forme d'un buffer (tableau 20x4) suivi d'un rafraichissement
de l'ecrant.

Contenu:


Auteur·e:
- Sleny Martinez (MAS)
- XXX XXX
"""


""" ------ Imports ------ """
# Gestion des exceptions etendue en cas de debug
if DEBUG_MODE: micropython.alloc_emergency_exception_buf(128)

# Imports bibliotheques interne
import machine
import time

# Imports bibliotheques externe officielle (lib)


# Imports bibliotheques externe maisons
import PCF8574




""" ------ Code Utile ------ """
" --- Initialisation --- "
_RS = None
_E = None
_BL = None
#_BL_PWM = None
_PCF_D = None

_LCD_buffer = {
1 : "                    " , # Ligne 1
2 : "                    " , # Ligne 2
3 : "                    " , # Ligne 3
4 : "                    "   # Ligne 4
}

def init (RS, E, BL, PCF8574):
    """
    Fonction: init (RS, E, BL, I2C)
    Definit les pins a utiliser (objet Pin ou I2C)
    """
    global _RS, _E, _BL, _PCF_D#, _BL_PWM
    _RS = RS
    _E = E
    _BL = BL
    #_BL_PWM = machine.PWM(_BL, freq=1000, duty=1023) if _BL != None else None
    _PCF_D = PCF8574

    # Procedure d'initialisation selon datasheet
    _E.value(1)
    time.sleep_ms(100)
    _send(0, 0x30)
    time.sleep_ms(5)
    _send(0, 0x30)
    time.sleep_us(200)
    _send(0, 0x30)
    time.sleep_us(200)
    _send(0, 0x38)
    _send(0, 0x10)
    _showDisplay()
    _send(0, 0x06)

    # Vidage Ecrant => Pret a commencer
    clearDisplay()


" --- Systeme --- "

def _send (RS, Datas):
    """
    Fonction: send (RS, D)
    Envoie des informations selon RS et Datas
    Gere l'application des Datas par I2C, de RS en
    directe et du flanc descendant de E
    """
    global _RS, _E, _BL, _PCF_D#, _BL_PWM

    # Envoi des donnes par I2C
    _PCF_D.write(Datas)
    # Application RS
    _RS.value(RS)
    # Mise a 1 de E (pour flanc descendant)
    _E.value(1)
    # Delais d'integration par l'ecrant
    time.sleep_us(1)
    # Validation des informations (flanc descendant E)
    _E.value(0)


def _showDisplay (C = False, B = False):
    """
    Fonction: _showDisplay (C = False, B = False)
    Allume l'ecrant
    Si C = True, le curseur sera visible
    Si B = True, le curseur clignottera
    De base, curseur invisible
    """
    data = 0x0C
    data = data + 0x2 if C is True else data
    data = data + 0x1 if B is True else data
    _send(0, data)


def _shiftCursor ():
    """
    Fonction: _shiftCursor ()
    Fait que le curseur se decale (pas l'ecrant) et
    que le tout s'ecrive de gauche a droite (ecriture latine)
    """
    _send(0, 0x14)




""" --- Actions ecrant pour utilisat·eur·rice """
def setBacklight (value):
    """
    Fonction: setBacklight (value = 100)
    Definit la luminosite du backlight, la valleur est True ou False
    """
    #global _BL_PWM
    #_BL_PWM.duty(int(value * 10.23))

    global _BL
    # Value: False => BL allume, True => BL eteint
    _BL.value(not value)

def getBuffer ():
    """
    Fonction: getBuffer ()
    Renvoie l'etat actuel du buffer
    """
    global _LCD_buffer
    return _LCD_buffer

def setBuffer (buffer):
    """
    Fonction: setBuffer ()
    Recois le nouvel etat du buffer
    Si ne corespond pas a une liste de 4 string de 20 caracteres,
    renvoie une erreur
    """
    global _LCD_buffer

    if type(buffer) != dict or \
    len(buffer) != 4 or \
    len(buffer[1]) != 20 or \
    len(buffer[2]) != 20 or \
    len(buffer[3]) != 20 or \
    len(buffer[4]) != 20:
        raise Exception("Donnees invalide, une liste de 4 string de 20 caracteres est requise.")
    else:
        _LCD_buffer = buffer

def setLine (line, text):
    """
    Fonction: setLine ()
    Modifie une ligne de l'ecrant
    Le texte doit faire au maximum 20 caracteres
    """
    text = str(text)
    buffer = getBuffer()
    buffer[line] = text + ((20 - len(text)) * " ") if len(text) <= 20 and type(text) == str else ""
    if buffer[line] == "": raise Exception("text doit etre un string de maximum 20 carateres de long.")
    setBuffer(buffer)

def setChar (line, pos, char):
    """
    Fonction: setChar ()
    Modifie le caracter a la ligne line et au rang pos, definit a char
    """
    global _LCD_buffer
    # On fait +1 pour que le premier char soit le N°1
    buffer = list(_LCD_buffer[line])
    buffer[pos - 1] = char
    nBuffer = ""
    for c in buffer:
        nBuffer += c
    _LCD_buffer[line] = nBuffer

def writeChar (char):
    """
    Fonction: _write_char (char)
    Ecrit un caracter a l'ecrant
    """
    _send(1, _getCharCGROMadress(char))

def writeLine (line, full = True):
    """
    Fonction: _writeLine (char)
    Ecrit une ligne
    Si full = False, ecrit seulement le texte demande, sinon remplis la ligne avec des espaces
    """
    line = str(line)
    if full:
        line = line + ((20 - len(line)) * " ") if len(line) <= 20 and type(line) == str else " " * 20
    else:
        line = line if len(line) <= 20 and type(line) == str else ""
    #print(line)
    for l in line:
        writeChar(l)

def clearDisplay ():
    """
    Fonction: clear_display ()
    Efface l'ecrant et met le curseur au debut
    """
    _send(0, 0x01)
    time.sleep_ms(1)

def fetch ():
    """
    Fonction: fetch ()
    Envoie le buffer a l'ecrant
    """
    # On commence par effacer totalement l'ecrant
    clearDisplay()

    # Puis on ecrit chaque char l'un apres l'autre
    # On doit faire dans l'ordre des lignes 1, 3, 2, 4 car
    # le curseur fait ce trajet (ref. au datasheet)
    for i in [1, 3, 2, 4]:
        for c in getBuffer()[i]:
            writeChar(c)

def setCursorPos (line, col):
    """
    Fonction: setCursorPos ()
    Deplace le curseur de l'ecrant a la position
    donnee par line (1 a 4) et col (1 a 20)
    """
    # Le deplacement se fait via la commande 0b1XXXXXXX
    # XXXXXXX correspond a la position (de 0x00 a 0x7F)
    # On commence par calculer cette valleur
    posAddress = 20 * [0, 0, 2, 1, 3][line]
    posAddress += col - 1
    # On aditionne a la commande de base
    command = 0x80 + posAddress
    # On envoie la valleur
    _send(0, command)
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

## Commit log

2019-06-04 Création projet KiCad
    [Projet.kicad_pcb, Projet.sch]
2020-08-25 Commande PCD 25.08.2020 midi
    [BOM.ods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]
2020-08-25 Soir 25.08.2020
    [BOM.ods]
2020-09-16 Writing Code
    [BOM.ods]
2020-09-22 Correcting for last version of HW
    [Clavier_RPN.py, PCF8574.py]
2020-10-09 MAJ Hardware
    [BOM.ods]
2021-01-11 Minior Edits
    [BOM.ods, file5FC15145.sch]
2021-01-22 Code complet: V1.0
    Publication de la première verssion complète du code (V1.0)
2021-01-22 Mise sous ZIP du HTML
    Mise sous zip des importants fichiers HTML de documentation

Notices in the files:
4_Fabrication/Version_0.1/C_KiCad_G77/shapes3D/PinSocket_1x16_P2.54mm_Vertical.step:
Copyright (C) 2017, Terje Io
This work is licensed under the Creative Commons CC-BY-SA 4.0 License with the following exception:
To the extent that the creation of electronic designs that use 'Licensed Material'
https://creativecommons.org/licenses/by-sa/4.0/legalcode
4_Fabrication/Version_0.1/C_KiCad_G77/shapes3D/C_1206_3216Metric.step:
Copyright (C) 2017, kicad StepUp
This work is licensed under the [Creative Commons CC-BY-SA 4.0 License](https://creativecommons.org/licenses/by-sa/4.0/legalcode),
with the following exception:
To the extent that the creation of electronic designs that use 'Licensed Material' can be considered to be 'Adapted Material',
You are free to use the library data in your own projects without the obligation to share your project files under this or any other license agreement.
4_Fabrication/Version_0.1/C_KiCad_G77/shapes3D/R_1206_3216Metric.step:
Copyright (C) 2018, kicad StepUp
